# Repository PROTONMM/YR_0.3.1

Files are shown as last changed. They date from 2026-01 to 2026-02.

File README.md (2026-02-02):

# PCB and Enclosure for the Yoradio Internet Radio

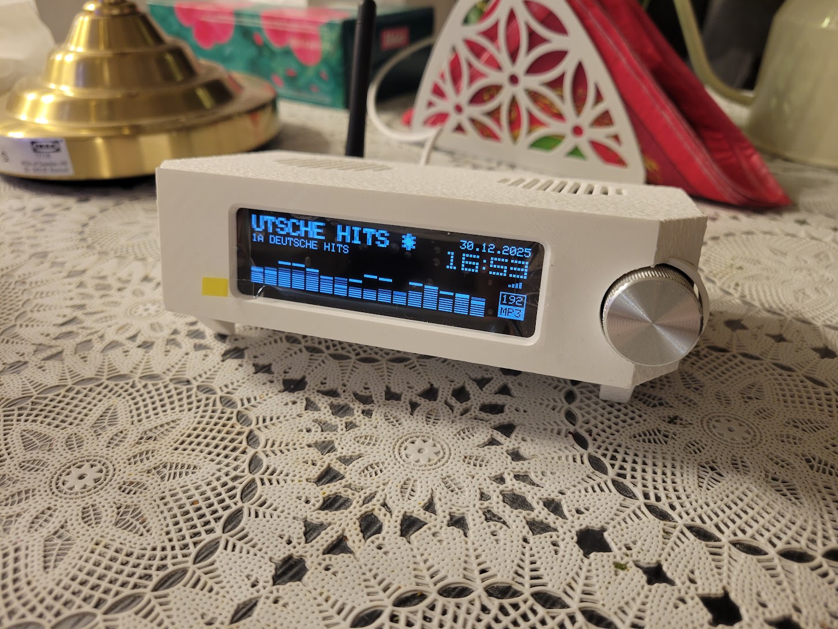
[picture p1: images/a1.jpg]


This project includes **only** the PCB and the enclosure; it does **not** include any software. MIT License.

<span style="color:red">**WARNING: This project is intended for advanced users. It is meant for further expansion and modification.**</span>

## Versions

Two enclosure versions are provided: one as a kitchen radio with speakers, and another with an RCA output for connecting to an external amplifier.

### RCA Version

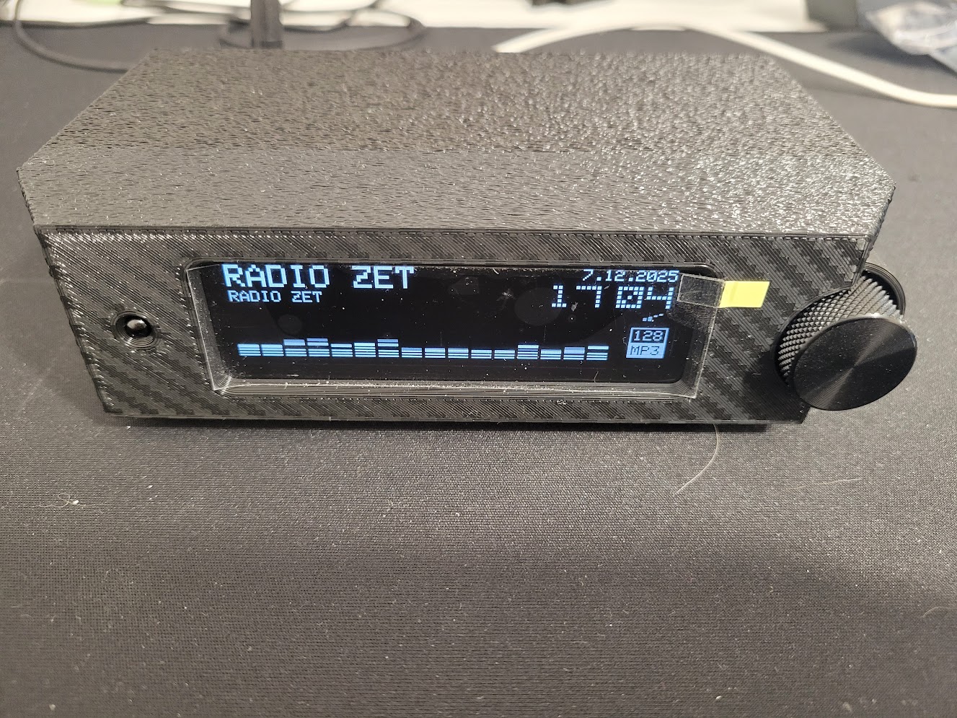
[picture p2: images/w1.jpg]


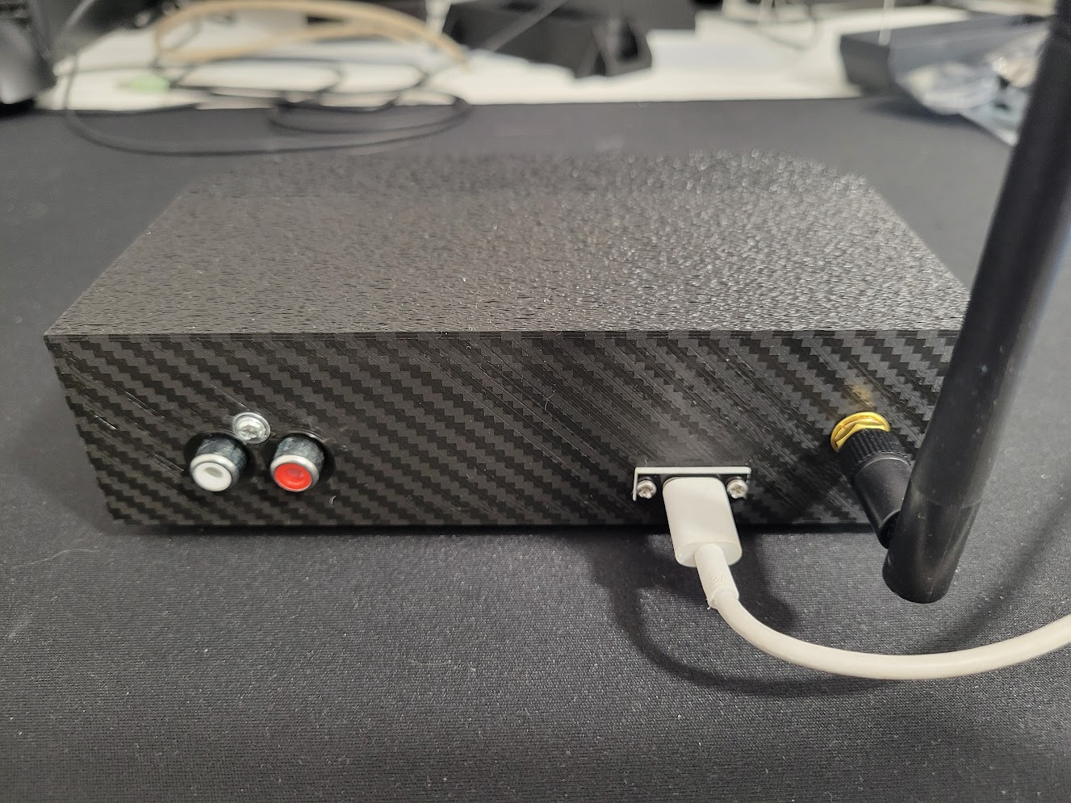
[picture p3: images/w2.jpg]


### With speakers version 

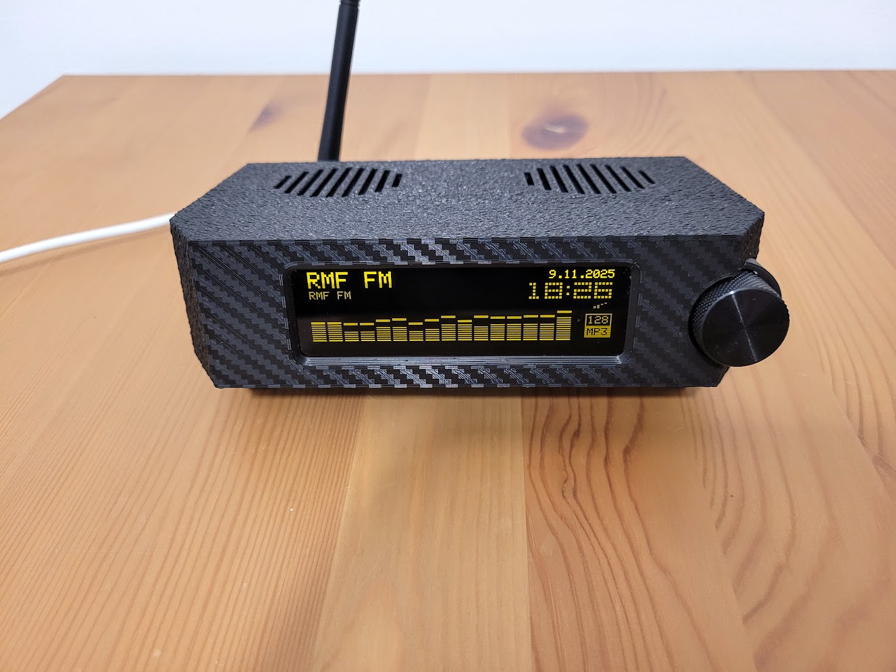
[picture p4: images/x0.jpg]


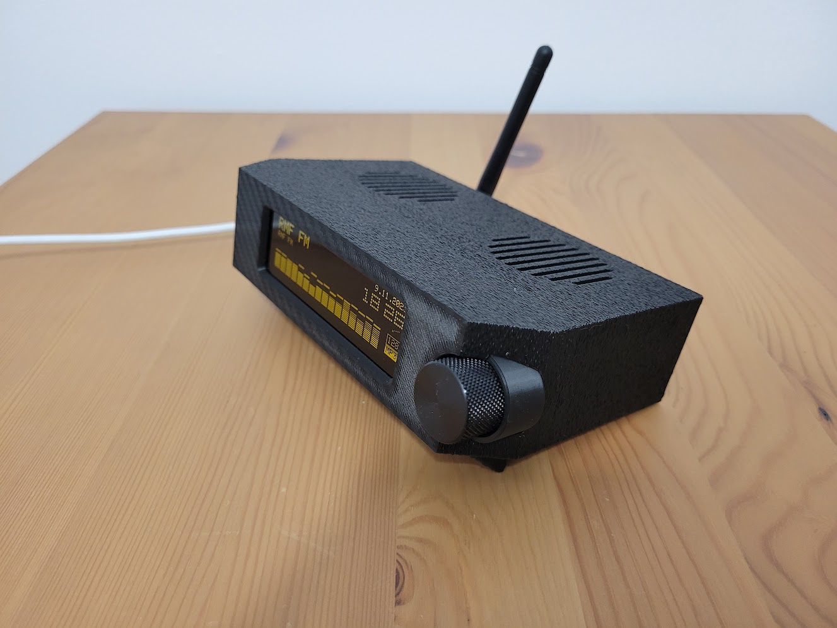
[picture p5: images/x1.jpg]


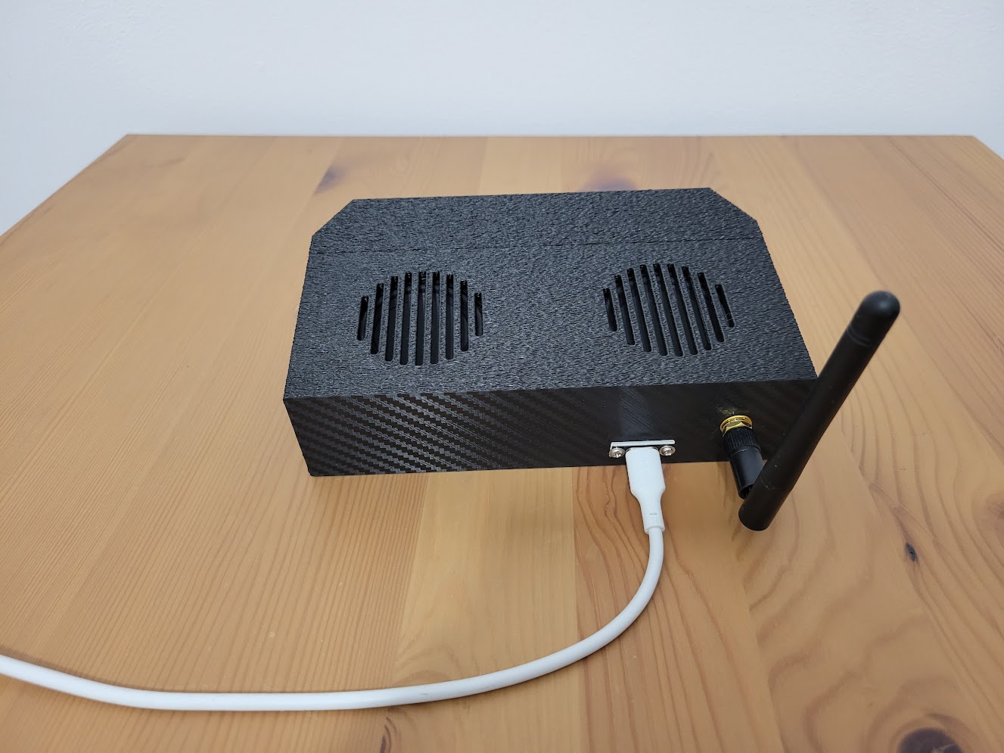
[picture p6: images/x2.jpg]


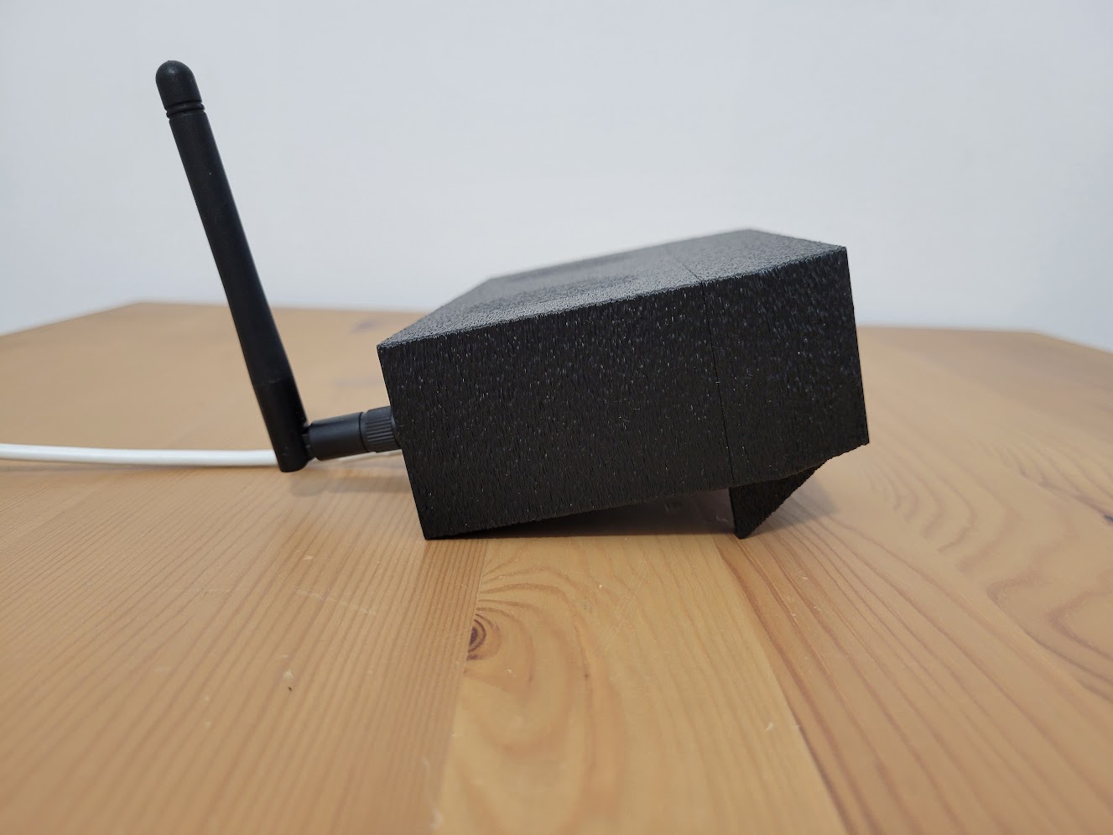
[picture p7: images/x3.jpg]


## Key components

The design was created around a few specific key parts; using other variants may require adjusting the enclosure and the PCB accordingly.

### Display

Only for SSD1322 display

### Encoder



https://pl.aliexpress.com/item/1005003534390893.html

### Knob

For the encoder above, you need the `Flower Shaped` variant.

 

https://pl.aliexpress.com/item/1005006912587864.html

### Speakers



https://pl.aliexpress.com/item/1005008571777367.html

### Less important parts

Personally, as the DAC and amplifier I used the **WeAct Studio I2S Speaker Module PCM5100A 4Ω 2.8W D Class Dual PA**.

https://pl.aliexpress.com/item/1005009660188314.html

### Acknowledgements

Special thanks to **Inżynier Programista** for help solving FreeCAD issues. Link to his YouTube channel: https://www.youtube.com/@InzynierProgramista

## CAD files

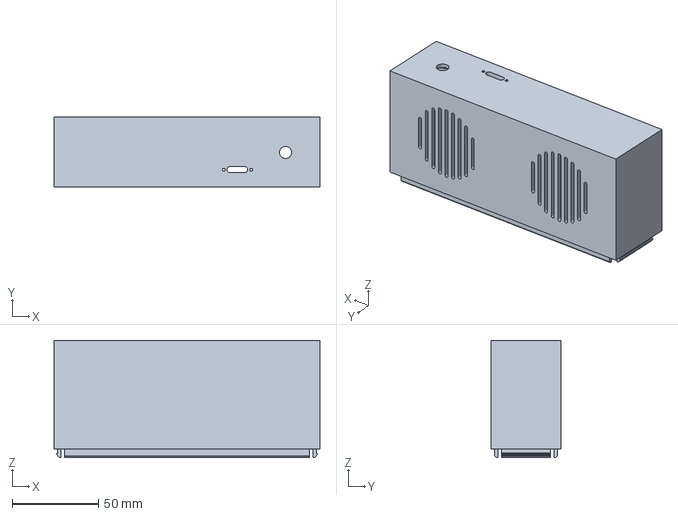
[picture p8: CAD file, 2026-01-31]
YR_CASE/exports/case_v3_6-Back_v2.3mf
154.5 x 40.5 x 68.0 mm

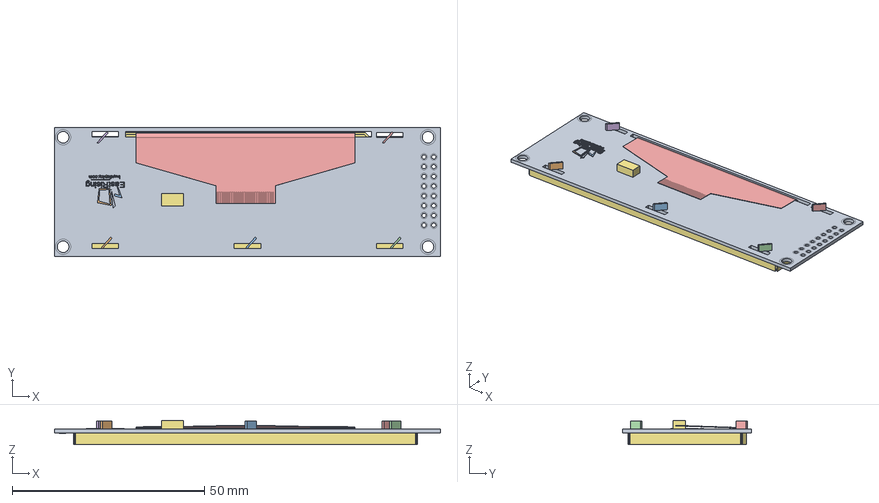
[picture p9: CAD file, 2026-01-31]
YR_CASE/YR_PCB/SSD1322.FCStd
100.5 x 33.5 x 6.30 mm
ER-OLEDM032-1_new
ER-OLEDM032-1_new001
ER-OLEDM032-1_new002
ER-OLEDM032-1_new003
ER-OLEDM032-1_new004
ER-OLEDM032-1_new005
ER-OLEDM032-1_new006
ER-OLEDM032-1_new007
ER-OLEDM032-1_new008
ER-OLEDM032-1_new009
ER-OLEDM032-1_new010
ER-OLEDM032-1_new011
ER-OLEDM032-1_new012
ER-OLEDM032-1_new013
ER-OLEDM032-1_new014
ER-OLEDM032-1_new015
ER-OLEDM032-1_new016
ER-OLEDM032-1_new017
ER-OLEDM032-1_new018
ER-OLEDM032-1_new019
ER-OLEDM032-1_new020
ER-OLEDM032-1_new021
ER-OLEDM032-1_new022
ER-OLEDM032-1_new023
ER-OLEDM032-1_new024
ER-OLEDM032-1_new025
ER-OLEDM032-1_new026
ER-OLEDM032-1_new027
ER-OLEDM032-1_new028
ER-OLEDM032-1_new029
ER-OLEDM032-1_new030
ER-OLEDM032-1_new031
ER-OLEDM032-1_new032
ER-OLEDM032-1_new033
ER-OLEDM032-1_new034
ER-OLEDM032-1_new035
ER-OLEDM032-1_new036
ER-OLEDM032-1_new037
ER-OLEDM032-1_new038
ER-OLEDM032-1_new039
ER-OLEDM032-1_new040
ER-OLEDM032-1_new041
ER-OLEDM032-1_new042
ER-OLEDM032-1_new043
ER-OLEDM032-1_new044
ER-OLEDM032-1_new045
ER-OLEDM032-1_new046
ER-OLEDM032-1_new047
ER-OLEDM032-1_new048
ER-OLEDM032-1_new049
ER-OLEDM032-1_new050
ER-OLEDM032-1_new051
ER-OLEDM032-1_new052
ER-OLEDM032-1_new053

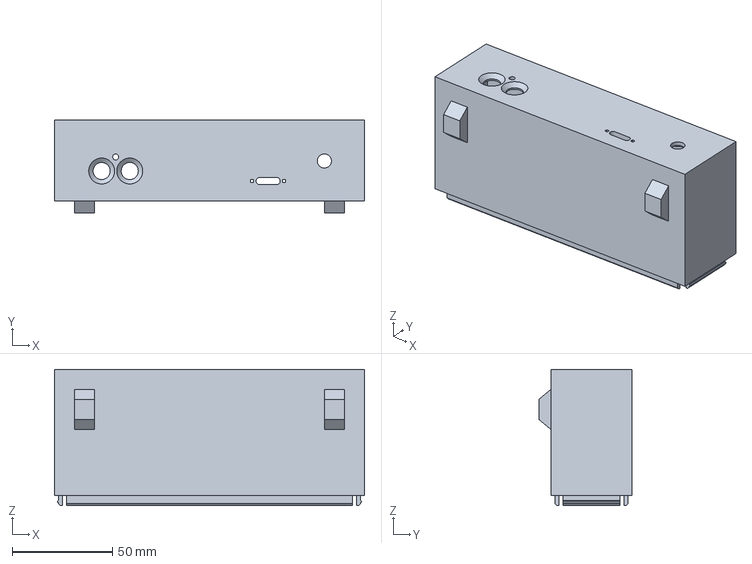
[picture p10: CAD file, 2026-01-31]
YR_CASE/exports/case_v3_7-Back.3mf
154.5 x 46.5 x 68.0 mm

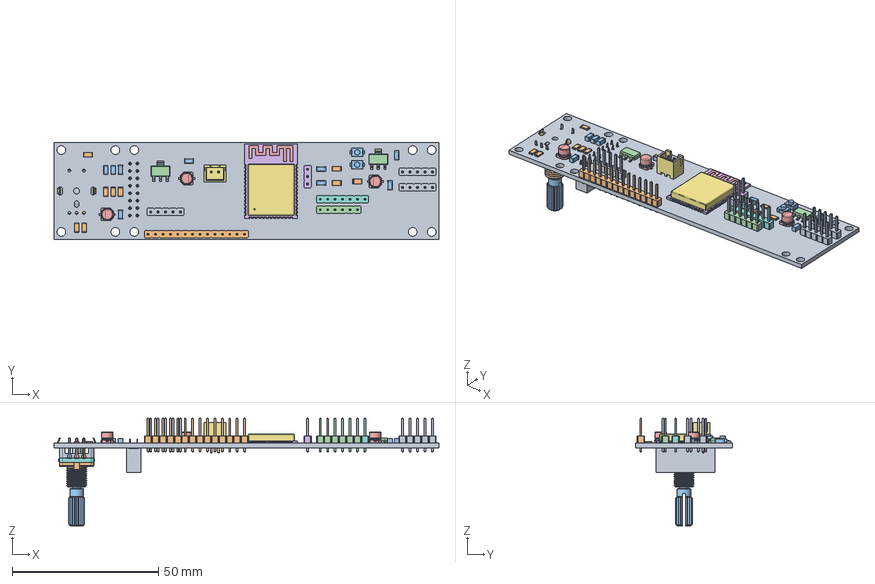
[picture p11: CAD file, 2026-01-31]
YR_CASE/YR_PCB/YR1.FCStd
131.8 x 33.1 x 36.8 mm
Pcb_ce90
R8_R_1206_3216Metric_849fe551dc66 x 9
C6_C_1206_3216Metric_5806ac7bf1ee x 9
U3_SOT-223_b71a6138f545 x 2
ESP32-S3-WROOM-1
ESP32-S3-WROOM-002
ESP32-S3-WROOM-003
ESP32-S3-WROOM-004
ESP32-S3-WROOM-005
ESP32-S3-WROOM-006
ESP32-S3-WROOM-007
ESP32-S3-WROOM-008
ESP32-S3-WROOM-009
ESP32-S3-WROOM-010
ESP32-S3-WROOM-011
ESP32-S3-WROOM-012
ESP32-S3-WROOM-013
ESP32-S3-WROOM-014
ESP32-S3-WROOM-015
ESP32-S3-WROOM-016
ESP32-S3-WROOM-017
ESP32-S3-WROOM-018
ESP32-S3-WROOM-019
ESP32-S3-WROOM-020
ESP32-S3-WROOM-021
ESP32-S3-WROOM-022
ESP32-S3-WROOM-023
ESP32-S3-WROOM-024
ESP32-S3-WROOM-025
ESP32-S3-WROOM-026
ESP32-S3-WROOM-027
ESP32-S3-WROOM-028
ESP32-S3-WROOM-029
ESP32-S3-WROOM-030
ESP32-S3-WROOM-031
ESP32-S3-WROOM-032
ESP32-S3-WROOM-033
ESP32-S3-WROOM-034
ESP32-S3-WROOM-035
ESP32-S3-WROOM-036
ESP32-S3-WROOM-037
ESP32-S3-WROOM-038
ESP32-S3-WROOM-039
ESP32-S3-WROOM-040
ESP32-S3-WROOM-041
ESP32-S3-WROOM-042
ESP32-S3-WROOM-043
ESP32-S3-WROOM-044
ESP32-S3-WROOM-045
ESP32-S3-WROOM-046
ESP32-S3-WROOM-047
ESP32-S3-WROOM-048
ESP32-S3-WROOM-049
ESP32-S3-WROOM-050
ESP32-S3-WROOM-051
ESP32-S3-WROOM-052
J5_PinHeader_1x05_P254mm_Vertical_ae4142e8ed21 x 3
J6_PinHeader_1x14_P254mm_Vertical_bfc407b08b14
S2_SW_SPST_TS-1088-xR025_609cbf66d0a0 x 2
J8_PinHeader_1x06_P254mm_Vertical_6df93f4f9b2e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

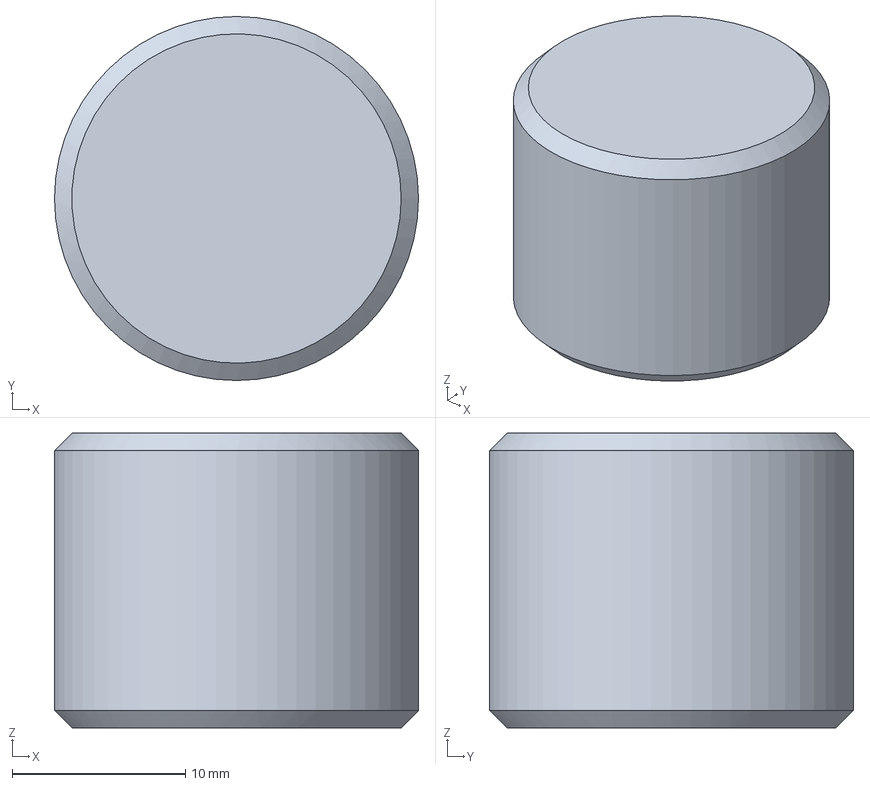
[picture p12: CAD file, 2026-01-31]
YR_CASE/YR_PCB/knob.FCStd
21.0 x 21.0 x 17.0 mm

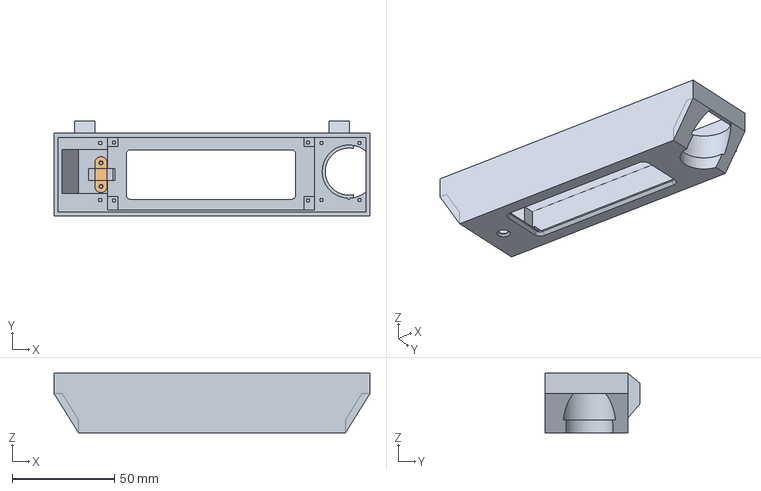
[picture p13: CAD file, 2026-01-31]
YR_CASE/case_v3_7.FCStd
154.5 x 46.5 x 29.2 mm
Front
ir-holder

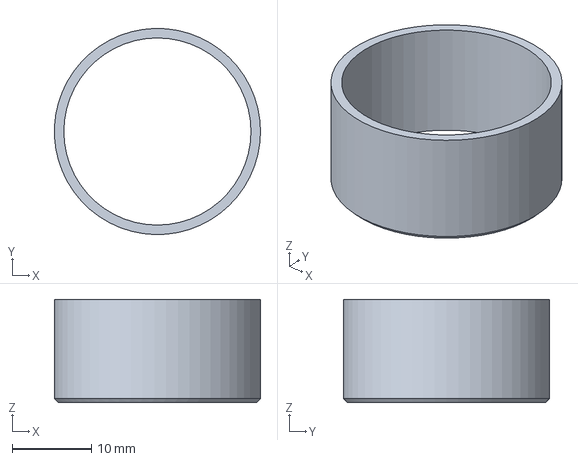
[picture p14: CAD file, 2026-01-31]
YR_CASE/exports/case_v3_4-Knob cover v2_3.3mf
26.0 x 26.0 x 13.0 mm

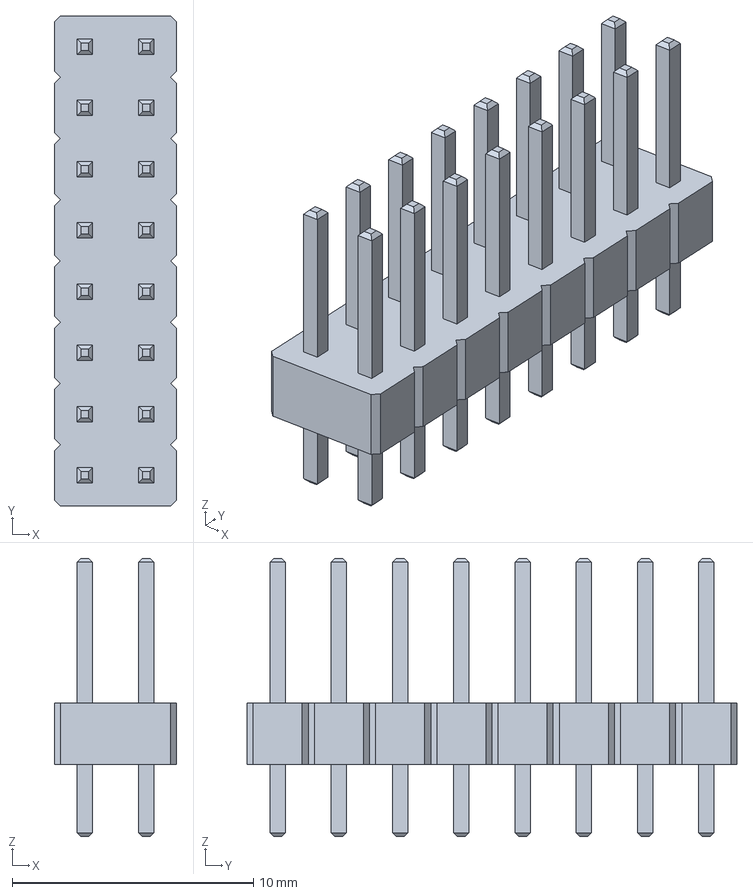
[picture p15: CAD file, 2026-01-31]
YR_CASE/YR_PCB/pin_header_2x08.FCStd
5.08 x 20.3 x 11.5 mm

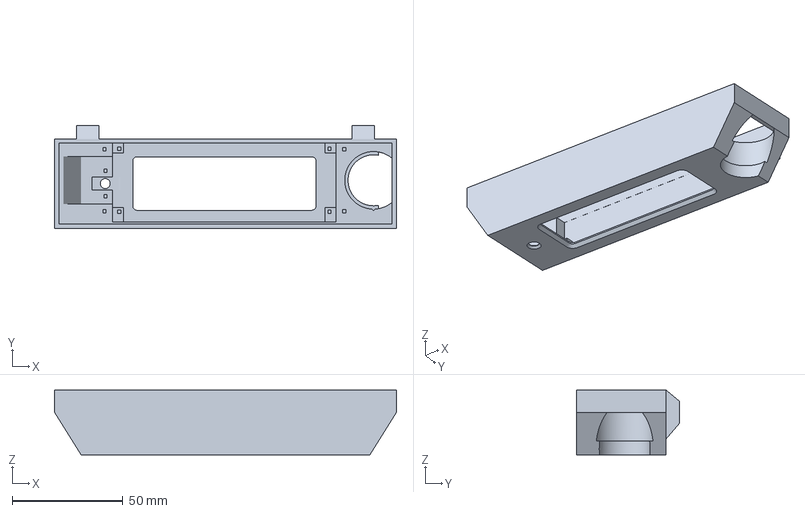
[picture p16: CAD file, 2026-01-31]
YR_CASE/exports/case_v3_7-Front-IR.3mf
154.5 x 46.5 x 29.2 mm

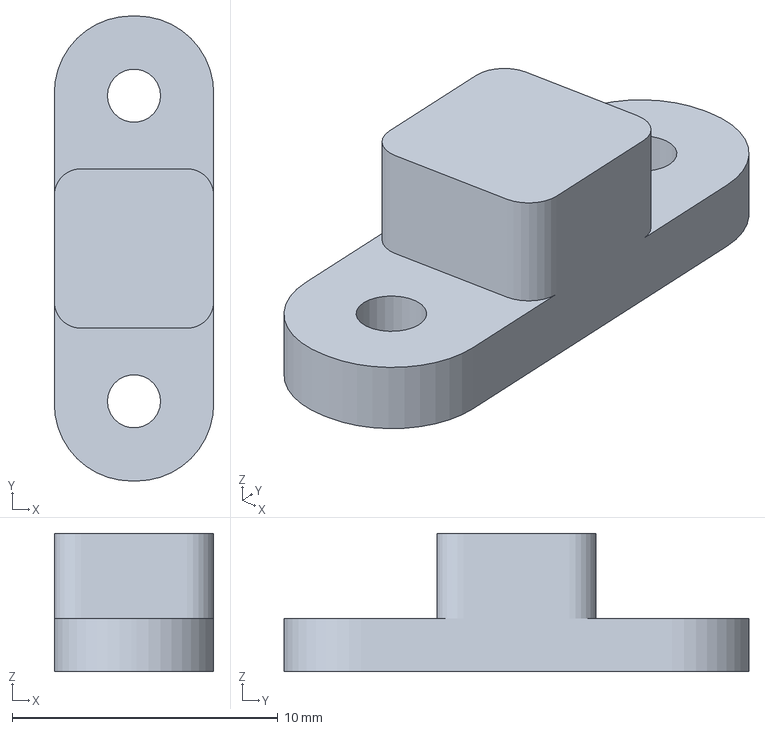
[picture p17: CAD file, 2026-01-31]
YR_CASE/exports/case_v3_7-ir-holder.3mf
6.00 x 17.5 x 5.20 mm

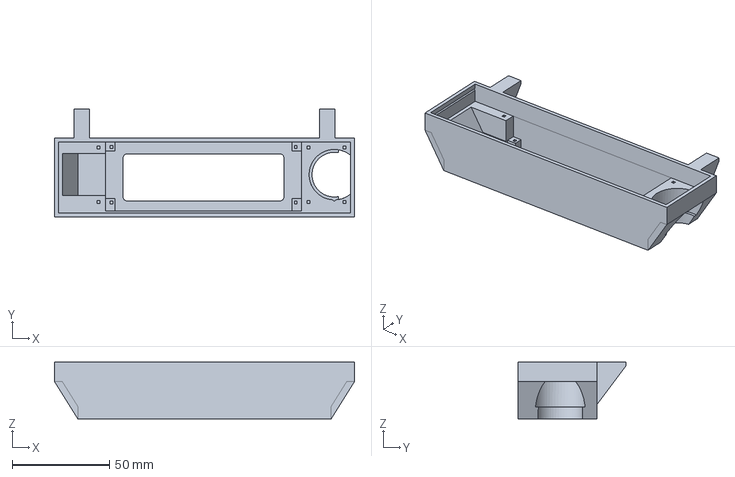
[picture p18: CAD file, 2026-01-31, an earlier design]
YR_CASE/case_v3_5.FCStd
154.5 x 55.5 x 29.2 mm

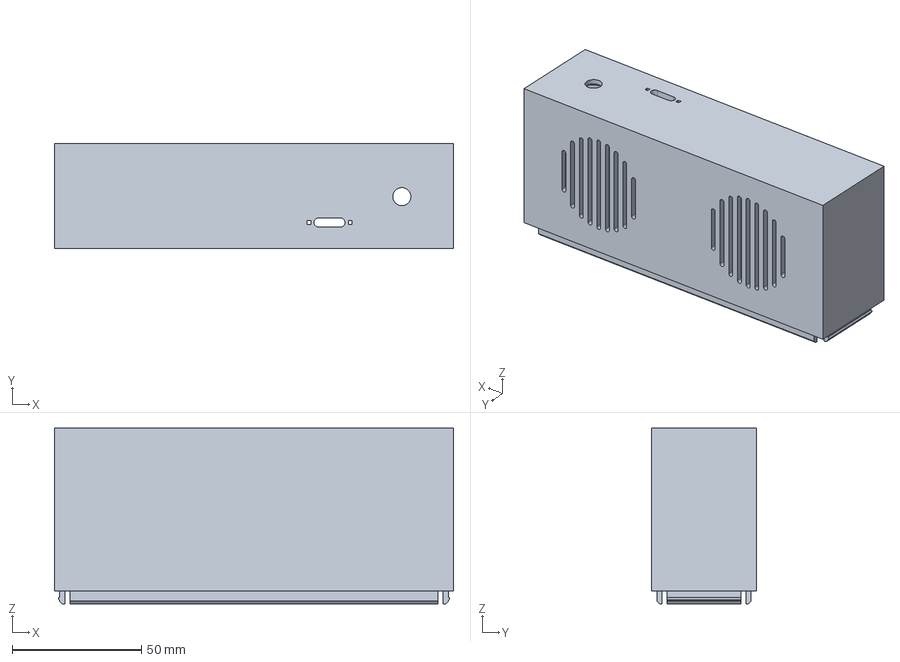
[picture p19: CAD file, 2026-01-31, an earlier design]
YR_CASE/case_v3_6.FCStd
154.5 x 40.5 x 68.0 mm

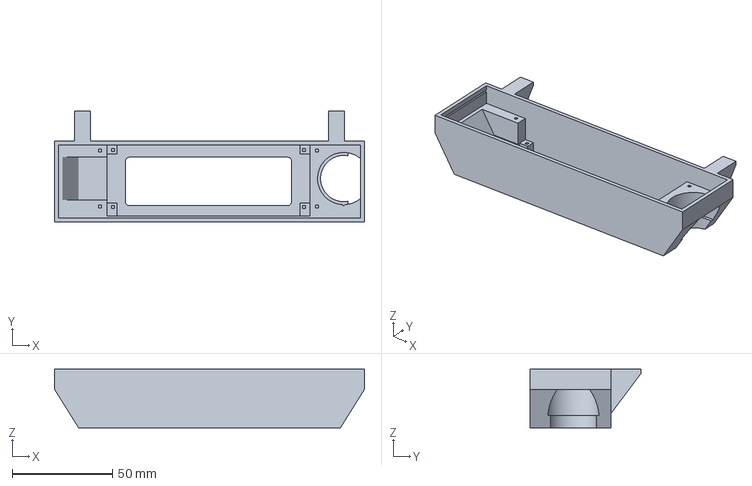
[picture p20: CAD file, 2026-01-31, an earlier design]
YR_CASE/exports/case_v3_5-Front.3mf
154.5 x 55.5 x 29.2 mm

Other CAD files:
YR_CASE/YR_PCB/YR_ASSEMBLED.FCStd
YR_CASE/exports/case_v3_7-Front.3mf
YR_CASE/case_v3_4.FCStd
YR_CASE/exports/case_v3_6-Back.3mf

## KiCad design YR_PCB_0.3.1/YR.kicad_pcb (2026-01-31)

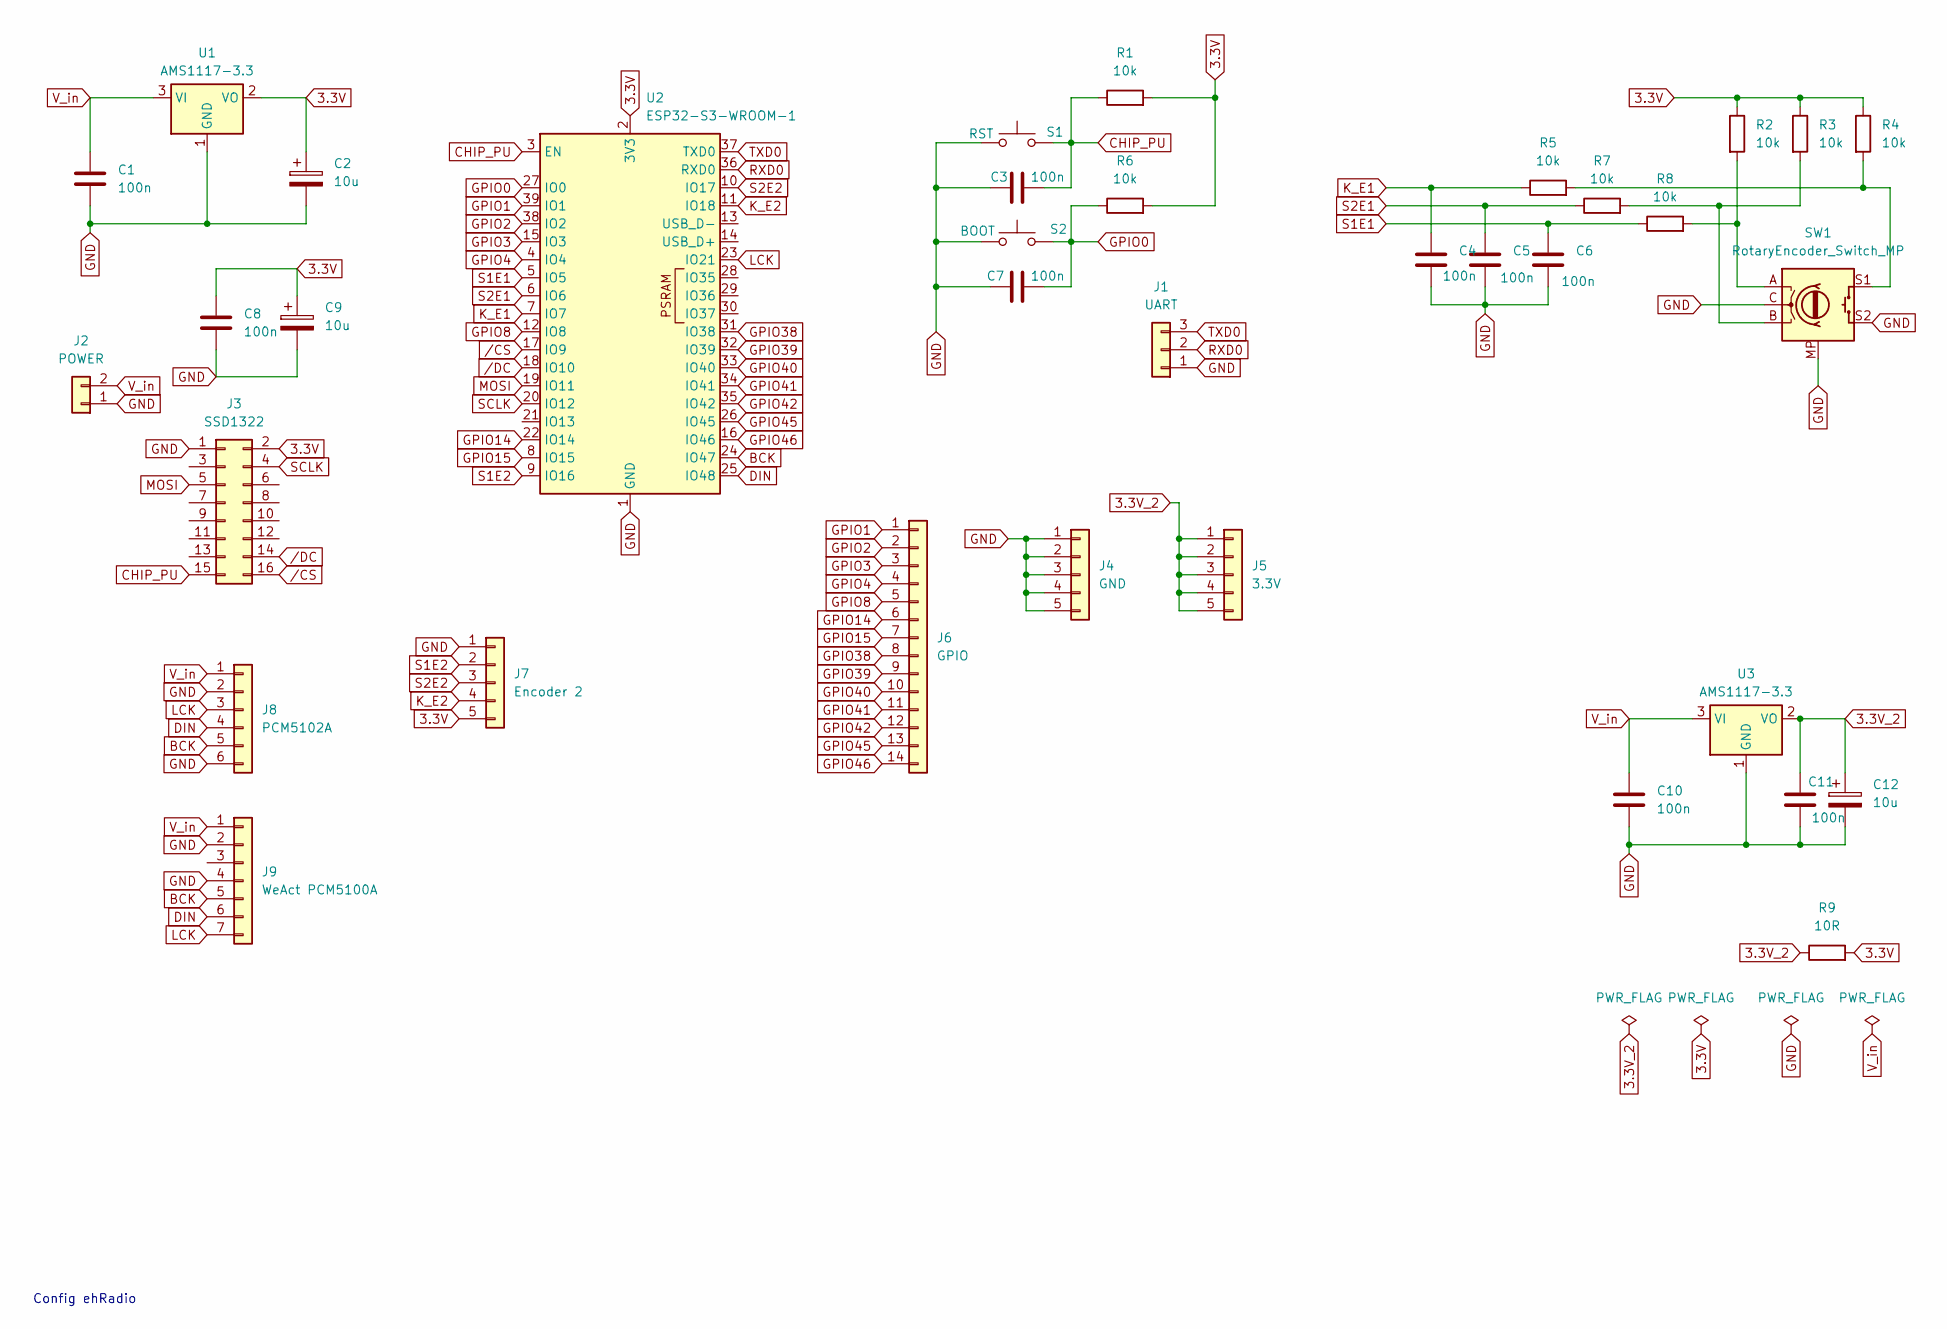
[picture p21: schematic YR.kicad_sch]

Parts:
C1, C3, C4, C5, C6, C7, C8, C10, C11: 100n; C_1206_3216Metric_Pad1.33x1.80mm_HandSolder
C2, C9, C12: 10u; CP_Elec_4x3.9
J1: UART; PinHeader_1x03_P2.54mm_Vertical
J2: POWER; JST_XH_B2B-XH-A_1x02_P2.50mm_Vertical
J3: SSD1322; PinSocket_2x08_P2.54mm_Vertical
J4: GND; PinHeader_1x05_P2.54mm_Vertical
J5: 3.3V; PinHeader_1x05_P2.54mm_Vertical
J6: GPIO; PinHeader_1x14_P2.54mm_Vertical
J7: Encoder 2; PinHeader_1x05_P2.54mm_Vertical
J8: PCM5102A; PinHeader_1x06_P2.54mm_Vertical
J9: WeAct PCM5100A; PinHeader_1x07_P2.54mm_Vertical
R1, R2, R3, R4, R5, R6, R7, R8: 10k; R_1206_3216Metric_Pad1.30x1.75mm_HandSolder
R9: 10R; R_1206_3216Metric_Pad1.30x1.75mm_HandSolder
S1: RST; SW_SPST_TS-1088-xR025
S2: BOOT; SW_SPST_TS-1088-xR025
SW1: RotaryEncoder_Switch_MP; RotaryEncoder_Alps_EC11E-Switch_Vertical_H20mm_CircularMoun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
U1, U3: AMS1117-3.3; SOT-223-3_TabPin2
U2: ESP32-S3-WROOM-1

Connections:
3.3V: C2.1, C8.1, C9.1, J3.2, J7.5, R1.2, R2.1, R3.1, R4.1, R6.2, R9.2, U1.2 (VO), U2.2 (3V3)
3.3V_2: C11.1, C12.1, J5.1, J5.2, J5.3, J5.4, J5.5, R9.1, U3.2 (VO)
BCK: J8.5, J9.5, U2.24 (IO47)
CHIP_PU: C3.2, J3.15, R1.1, S1.2, U2.3 (EN)
DIN: J8.4, J9.6, U2.25 (IO48)
GND: C1.2, C2.2, C3.1, C4.2, C5.2, C6.2, C7.1, C8.2, C9.2, C10.2, C11.2, C12.2, J1.1, J2.1, J3.1, J4.1, J4.2, J4.3, J4.4, J4.5, J7.1, J8.2, J8.6, J9.2, J9.4, S1.1, S2.1, SW1.C, SW1.MP, SW1.S2, U1.1 (GND), U2.1 (GND), U2.40 (GND), U2.41 (GND), U3.1 (GND)
GPIO0: C7.2, R6.1, S2.2, U2.27 (IO0)
GPIO1: J6.1, U2.39 (IO1)
GPIO2: J6.2, U2.38 (IO2)
GPIO3: J6.3, U2.15 (IO3)
GPIO4: J6.4, U2.4 (IO4)
GPIO8: J6.5, U2.12 (IO8)
GPIO14: J6.6, U2.22 (IO14)
GPIO15: J6.7, U2.8 (IO15)
GPIO38: J6.8, U2.31 (IO38)
GPIO39: J6.9, U2.32 (IO39)
GPIO40: J6.10, U2.33 (IO40)
GPIO41: J6.11, U2.34 (IO41)
GPIO42: J6.12, U2.35 (IO42)
GPIO45: J6.13, U2.26 (IO45)
GPIO46: J6.14, U2.16 (IO46)
K_E1: C4.1, R5.1, U2.7 (IO7)
K_E2: J7.4, U2.11 (IO18)
LCK: J8.3, J9.7, U2.23 (IO21)
MOSI: J3.5, U2.19 (IO11)
unnamed: R2.2, R8.2, SW1.A
unnamed: R3.2, R7.2, SW1.B
unnamed: R4.2, R5.2, SW1.S1
RXD0: J1.2, U2.36 (RXD0)
S1E1: C6.1, R8.1, U2.5 (IO5)
S1E2: J7.2, U2.9 (IO16)
S2E1: C5.1, R7.1, U2.6 (IO6)
S2E2: J7.3, U2.10 (IO17)
SCLK: J3.4, U2.20 (IO12)
TXD0: J1.3, U2.37 (TXD0)
V_in: C1.1, C10.1, J2.2, J8.1, J9.1, U1.3 (VI), U3.3 (VI)
/CS: J3.16, U2.17 (IO9)
/DC: J3.14, U2.18 (IO10)

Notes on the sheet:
Config ehRadio

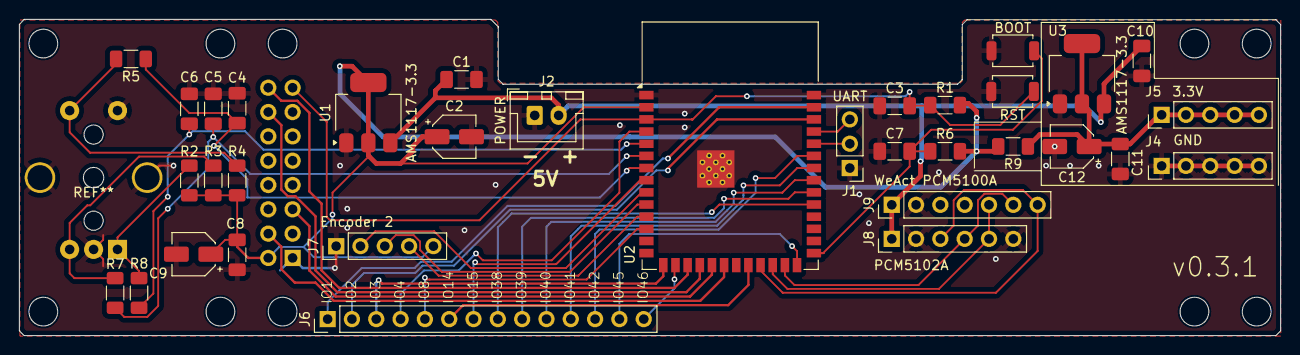
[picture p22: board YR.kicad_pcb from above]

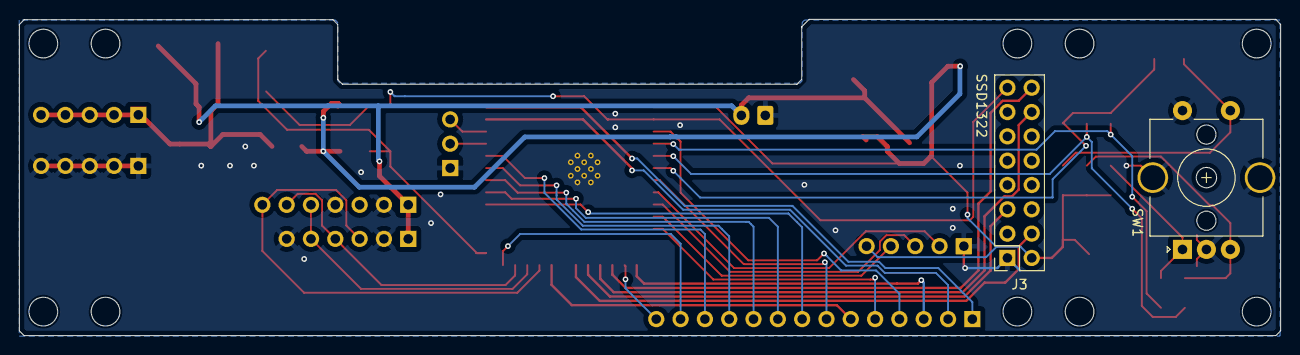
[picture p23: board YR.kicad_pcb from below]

Board: 2 copper layers, 131.8 x 33.0 mm, 36 parts (2 on the bottom side), 38 nets.

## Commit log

2026-01-31 added PCB
    [YR.kicad_pcb, YR.kicad_sch]
2026-01-31 added FreeCAD cases projects
    [SSD1322.FCStd, YR1.FCStd, YR_ASSEMBLED.FCStd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]
